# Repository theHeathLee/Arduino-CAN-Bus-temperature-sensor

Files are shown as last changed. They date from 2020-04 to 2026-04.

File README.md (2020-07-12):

# Arduino CAN Bus temperature sensor
Arduino with a can transceiver and k type temperature probe. that is all.

Range 0°C to +1024°C

For use with cyclinder head temperature (CHT) Exhaust gas temperatur (EGT) Water/Coolant etc. 

Galvanic isolation so sensor can be mounted to vehicle ground without any ground loop issues.

## Parts:

Arduino Nano

- Max6675

- MCP2515

- ADUM5401

- x2 1μF Capacitors

- [3D Printed Enclosure](https://www.thingiverse.com/thing:4293410)

- [x2 JST JWPF Sockets](https://www.jst-mfg.com/product/detail_e.php?series=151)

- x4 10x5mm neodymium magnets

External Libraries:
- [MCP_can - Coryjfowler](https://github.com/coryjfowler/MCP_CAN_lib)
- [Max6675 - SiriUli(Adafruit Fork)](https://github.com/SirUli/MAX6675)

## CAN Matrix

Baud: 250Kbs

| Value | ID |DLC | Byte Pos.|
| --- |:-----:  |----: | --:|
| Temp (C) | 0x100 | 8 | 0 |
## Prototype

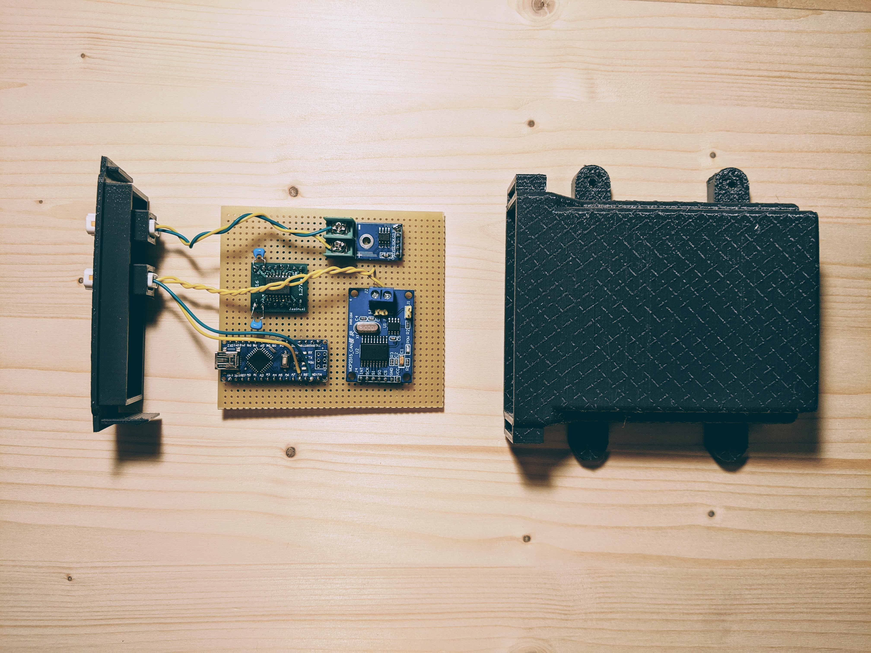
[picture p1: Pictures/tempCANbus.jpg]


Connected oldtimer banner

## Diagrams

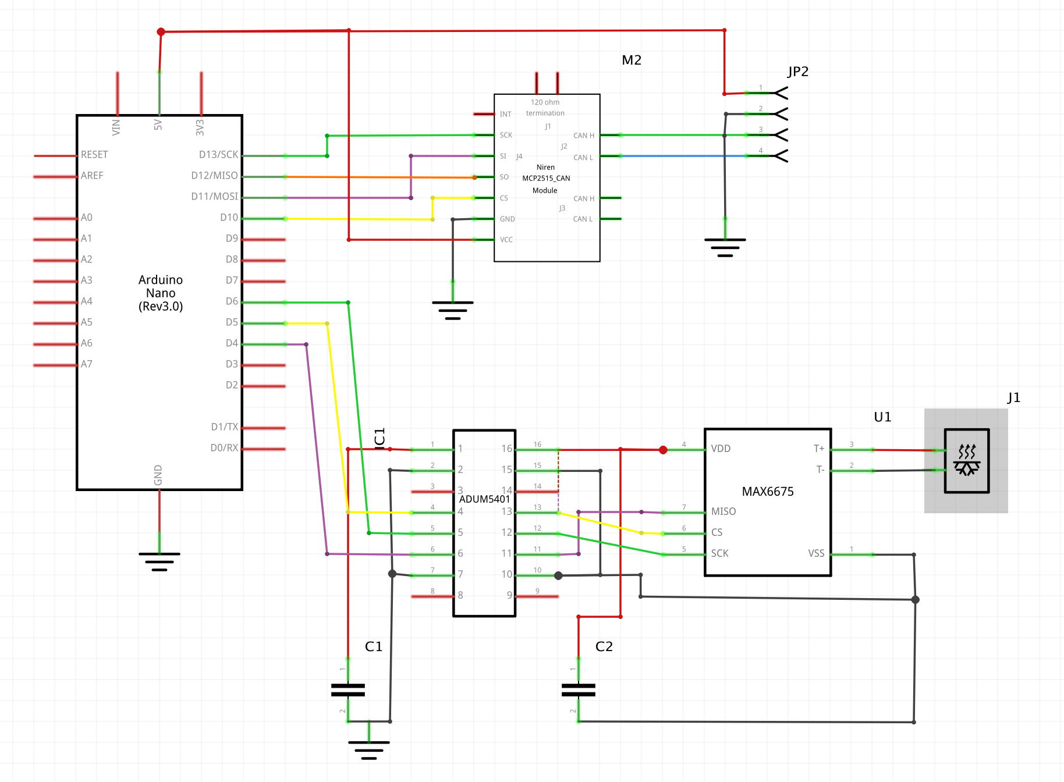
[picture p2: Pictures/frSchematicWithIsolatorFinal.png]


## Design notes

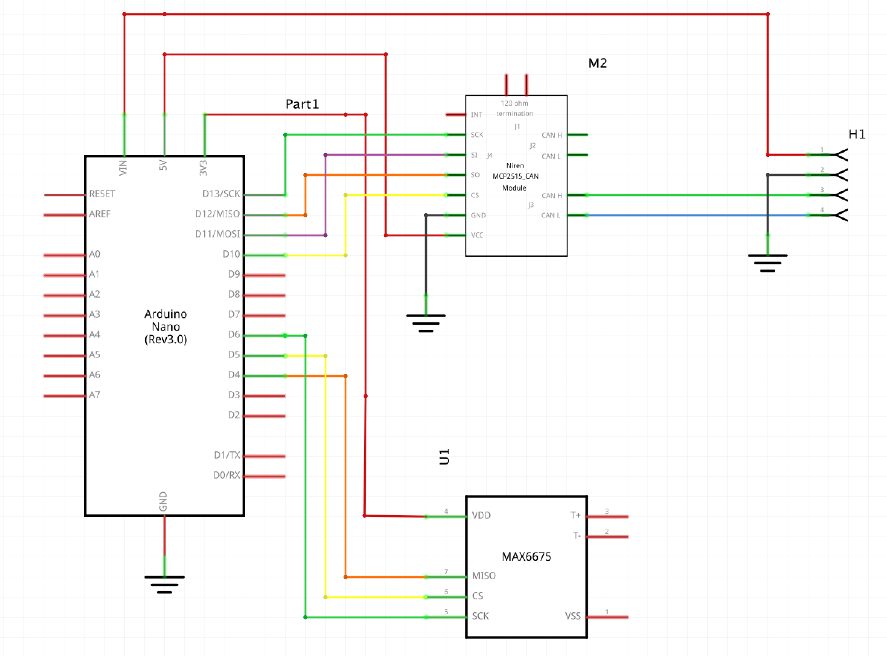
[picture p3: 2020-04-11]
Pictures/frSchematic.png

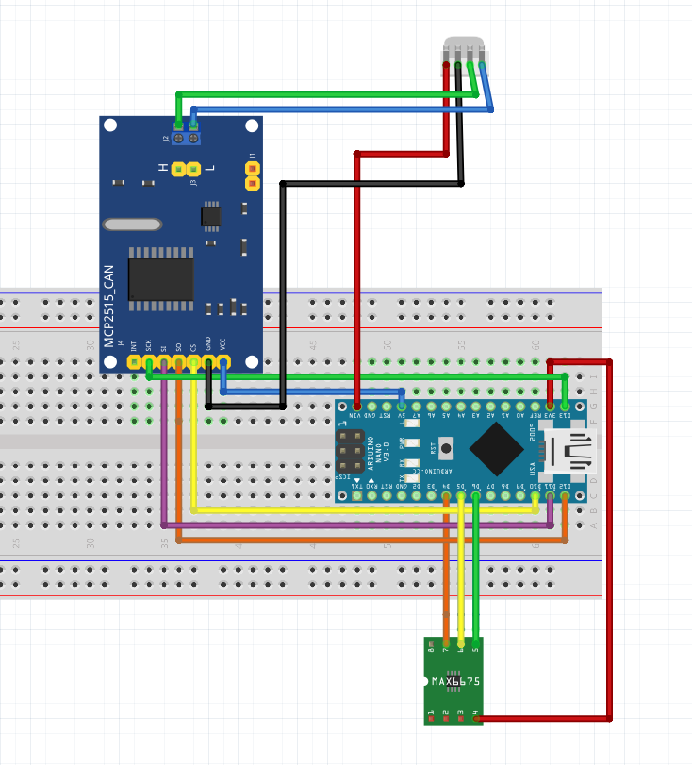
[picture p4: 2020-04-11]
Pictures/frBreadboared.png

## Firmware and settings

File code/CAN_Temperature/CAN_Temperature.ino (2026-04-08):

#include <mcp_can.h>
#include <SPI.h>
#include "max6675.h"

// old temp was 28 at room temperature of 21 and 100 at boiling water
#define tempScaler 1  //.825
// oil pressure sensor using balance bridge with reference resistor of 320 ohms
#define oilPressureResistanceCal .598

int thermoDO = 4;
int thermoCS = 5;
int thermoCLK = 6;
MAX6675 thermocouple(thermoCLK, thermoCS, thermoDO);
int oilSensorPin = A0;

int16_t temperatureCelcius = 0;
uint8_t oilPressure = 0;
uint8_t oilPressureraw = 0;


MCP_CAN CAN0(10);  // Set CS to pin 10

void setup() {

  Serial.begin(9600);

  // Initialize MCP2515 running at 8MHz with a baudrate of 250kb/s and the masks and filters disabled.
  if (CAN0.begin(MCP_ANY, CAN_250KBPS, MCP_8MHZ) == CAN_OK) Serial.println("MCP2515 Initialized Successfully!");
  else Serial.println("Error Initializing MCP2515...");
  CAN0.setMode(MCP_NORMAL);  // Change to normal mode to allow messages to be transmitted

  // wait for MAX chip to stabilize
  delay(500);
}



void loop() {
  temperatureCelcius = int16_t(thermocouple.readCelsius());
  oilPressureraw = analogRead(oilSensorPin) * oilPressureResistanceCal;
  //convert from resistance range to psi range
  oilPressure = map(oilPressureraw, 0, 184, 0, 72);
  Serial.print("C = ");
  Serial.print(temperatureCelcius);
  //Serial.print(thermocouple.readCelsius());
  Serial.print("   ");
  Serial.print("Oil Pressure: ");
  Serial.println(oilPressure);
  delay(100);

  byte data[8] = { temperatureCelcius & 0x00FF, oilPressure, 0xFF, 0xFF, 0xFF, 0xFF, 0xFF, 0xFF };

  // send data:  ID = 0x100, Standard CAN Frame, Data length = 8 bytes, 'data' = array of data bytes to send
  byte sndStat = CAN0.sendMsgBuf(0x100, 0, 8, data);
  if (sndStat == CAN_OK) {
    //Serial.println("Message Sent Successfully!");
  } else {
    //Serial.println("Error Sending Message...");
  }
  delay(100);
}

/*********************************************************************************************************
  END FILE
*********************************************************************************************************/

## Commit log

2020-04-11 add fritzing project
    [TemperatureCAN.fzz]
2020-04-11 update fritzing
    [TemperatureCAN.fzz]
2020-04-14 add temp offset calibration
2020-07-11 added isolator to schematic
2020-07-12 added ground to diagram
2020-07-12 Change temperature val to signed 16 bit int
2020-07-12 added fritzing file
    [CANtempSensor.fzz]
2021-03-14 add basic oil pressure input
2024-02-17 add code for oil pressure in psi
